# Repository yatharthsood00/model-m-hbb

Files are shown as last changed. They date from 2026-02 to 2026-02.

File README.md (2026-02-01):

# Model M Controller, by HBB

This is a drop-in replacement controller for the IBM Model M with QMK and VIAL support. I designed this for myself, and my own Models M, as well as some that I have sold/gifted to friends in the custom keyboard community, which is why this is designed only for the Models M that I own (the 101 key ANSI version, and the Space Saving Keyboard).

**Status (01-02-2026):** PCBA produced via JLCPCB and delivered. Tested successfully for basic operation. JST connector assembly in progress (I don't have a hot air soldering station).

## TODO:

1. Testing status lights and buzzer operation.
2. Uploading QMK and VIAL source to their respective repos.
3. BOM list availability in README (this file).
4. Fitment issue resolution due to USB-C port being too low for the existing cutout.
5. Figuring out solenoid operation and components required.
6. Pictures.

## Specs

- Based on the STM32F072CBT6 microcontroller, wide availability and great pedigree with QMK and VIAL. Works over USB-C.
- Like said, QMK and VIAL compatibility (firmware push and merge pending but it'll be there).
- Buzzer and Solenoid compatibility (optional, WIP). The exact parts needed for the solenoid are TBD and testing is required to be done first.
- Custom Status Lights PCB for adding LEDs in the colours of your choosing (standard DIP LEDs only), for the variants that have the possibility of adding such lights.
- Compatible with the 101-key and SSK Models M, Terminal or PS/2, both ANSI and ISO* versions.

*I need help with the firmware, as I don't own an ISO Model M to test it on.

## Why a new controller?

The "replacement Model M Controller" idea has already been implemented by many projects, with them already doing the work on understanding how the controller can be made in the first place, and the dimensions of a board that will fit the space voided by the original controller, that would be necessary to know how to place the components on my replacement. With that in mind, I would like to specifically highlight the [Ctrl-M](https://github.com/nuess0r/ctrl-M) and the [Model H](https://github.com/jhawthorn/modelh) projects, as they both provided me a sanity check of the dimensions of the PCB that I needed to design, separate from my own measurements of the several OEM controllers I now own.

While the above two are perfectly capable equivalents of my own creation, and I'm sure many would find either more suited for their own use cases, I found some limitations with the both of them that were disqualifying for my own use. Here is what I needed:

1. USB-C. All my other keyboards work off the same USB-C cable that I can detach from the keyboard end and swap the keyboard on my desk with another. While the Model H had this ability with the right Pro Micro controller, the Ctrl-M did not.
2. PCBA. It's significantly more expensive to produce this PCB via JLCPCB, with or without their assembly service. It's also almost conventional to expect a vintage keyboard replacement part to use a more "period-accurate" part selection, with through-hole componentry wherever possible, but I wanted something more modern that resembled a keyboard PCB you would get with a custom keyboard today. An entirely vain addition.
3. Additional bells and whistles. A keyboard with a solenoid is something I always wanted to add to my collection. While there are modern boards that will provide that to you, they are superseded, in my opinion, by a roomy plastic chassis, from a time when keyboards were normally significantly louer. Neither of the existing modules could provide that to me without a significant modification, so I decided to start from scratch.

Note: As a starting point for the solenoid and buzzer, I took directly from the [M122ion Control](https://github.com/dcpedit/mission-control) project, although the end result will use different components for the switching circuit.

All the above are fulfilled by this controller. This is also my first PCB design, and I enjoyed working on it. 

**As a disclaimer, however,** I don't claim this to be an extremely competent component, and I would advise anyone thinking of ordering a production run of this PCB to do their due diligence first. This is a hobbyist project first of all. Nonetheless, don't hesitate to reach out to me on @hardbodybrain on Discord, or on my personal email ID, yatharthsood00 [at] gmail [dot] com for any questions or clarifications, as well as if you want to share your experiences with this PCB, if you chose to get one of your own!

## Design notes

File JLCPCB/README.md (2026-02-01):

# JLCPCB Production Files

There are two folders - one for the Gerber files for the controller itself, and the other for the status lights PCB Gerber files. You can skip the latter if you own an SSK or a Terminal model with no ability to display any status LEDs.

Both these folders contain the same files I used for the first production run of this PCB, in January 2026. Read the main README.md file for information on the run's outcomes and how the PCBs fared in my testing.

### Controller PCB

- Expected to be PCBA. 
- Uses SMD components wherever possible. You are expected to mandatorily solder the ribbon connector receptacles, I didn't hold my breath for JLCPCB having them in their components library. 
- All solenoid parts (except for the solenoid JST) are also through-hole, as I was not sure about which ones to use to make the solenoid work when I placed the order.
- The STM32 microcontroller chip will come with the USB-based bootloader in my experience when ordered from JLCPCB, but the board lacks exposed serial debug pins which you need in case you don't have a controller with the required bootloader, requiring you to solder some wires to the chip directly (tricky business).
- All the settings are all the defaults from JLCPCB that automatically populate when you upload the production files archive, except for the surface finish (I went with lead-free HASL, although that limits you on colour choices).

### Status lights
- Expected not PCBA, but you will have to solder the JST yourself if not. If money is no object, you can pay the hefty fees to solder one (1) singular component on this board through the assembly service. 
- All other parts are THT and trivial to assemble yourself. You can pick your status LEDs and read their datasheets for knowing what resistance would be best to work with.
- All default JLCPCB settings. 

More information will be added as I can add it based on my own experiences with this PCB.

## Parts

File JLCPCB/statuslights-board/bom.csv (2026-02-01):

Designator | Footprint | Quantity | Value | LCSC Part #
CAPSLED, NUMLED, SCRLED | LED_D5.0mm | 3 | LED
CAPSR, NUMR, SCRR | R_Axial_DIN0204_L3.6mm_D1.6mm_P1.90mm_Vertical | 3 | 51R
J1 | JST_SH_BM04B-SRSS-TB_1x04-1MP_P1.00mm_Vertical | 1 | JST SH (from controller)

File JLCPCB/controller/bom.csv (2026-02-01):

Designator | Footprint | Quantity | Value | LCSC Part #
BZ1 | Buzzer_12x9.5RM7.6 | 1 | Buzzer
C1 | 0402 | 1 | 10uF | C52923
C10, C11, C2 | 0402 | 3 | 1uF | C52923
C3, C6, C8 | 0402 | 3 | 4.7uF
C4, C5, C7, C9 | 0402 | 4 | 100nF
D1 | D_DO-41_SOD81_P2.54mm_Vertical_AnodeUp | 1 | ~
D2 | SOT-143 | 1 | PRTR5V0U2X
F1 | 1206 | 1 | ASMD1206-050
J1 | USB_C_Receptacle_HRO_TYPE-C-31-M-12 | 1 | USB_C_Receptacle_USB2.0_16P
J2 | PinHeader_1x16_P2.54mm_Vertical | 1 | Conn_01x16_Socket
J3 | PinHeader_1x08_P2.54mm_Vertical | 1 | Conn_01x08_Socket
J4 | JST_SH_BM04B-SRSS-TB_1x04-1MP_P1.00mm_Vertical | 1 | JST SH 4-pin
J5 | JST_SH_BM02B-SRSS-TB_1x02-1MP_P1.00mm_Vertical | 1 | JST SH 2-pin
Q1 | SOT-23 | 1 | 2N7002
Q2 | TO-220-3_Vertical_BCE | 1 | ~
R1, R2 | 0402 | 2 | 5.1K
R3 | 0402 | 1 | 10K
R4 | 0402 | 1 | 100K
R5 | 0402 | 1 | 33K
R6, R7 | R_Axial_DIN0204_L3.6mm_D1.6mm_P1.90mm_Vertical | 2 | ~
SW1 | SW_Push_1P1T_XKB_TS-1187A | 1 | TS-1187A-B-A-B
U1 | SOT-23 | 1 | XC6206P332MR
U2 | LQFP-48_7x7mm_P0.5mm | 1 | STM32F072CBT6

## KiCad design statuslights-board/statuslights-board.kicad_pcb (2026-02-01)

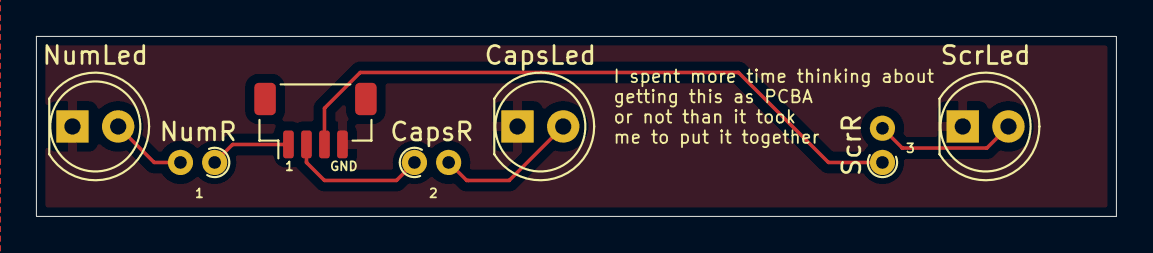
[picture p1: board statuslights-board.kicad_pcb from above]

Board: 2 copper layers, 60.0 x 10.0 mm, 7 parts (0 on the bottom side), 7 nets.

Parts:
CapsLed: LED; LED_D5.0mm
CapsR: 51R; R_Axial_DIN0204_L3.6mm_D1.6mm_P1.90mm_Vertical
J1: JST SH (from controller); JST_SH_BM04B-SRSS-TB_1x04-1MP_P1.00mm_Vertical
NumLed: LED; LED_D5.0mm
NumR: 51R; R_Axial_DIN0204_L3.6mm_D1.6mm_P1.90mm_Vertical
ScrLed: LED; LED_D5.0mm
ScrR: 51R; R_Axial_DIN0204_L3.6mm_D1.6mm_P1.90mm_Vertical

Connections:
CapsLk: CapsR.1, J1.2
GND: CapsLed.1 (K), J1.4, NumLed.1 (K), ScrLed.1 (K)
unnamed: CapsLed.2 (A), CapsR.2
unnamed: NumLed.2 (A), NumR.2
unnamed: ScrLed.2 (A), ScrR.2
NumLk: J1.1, NumR.1
ScrLk: J1.3, ScrR.1

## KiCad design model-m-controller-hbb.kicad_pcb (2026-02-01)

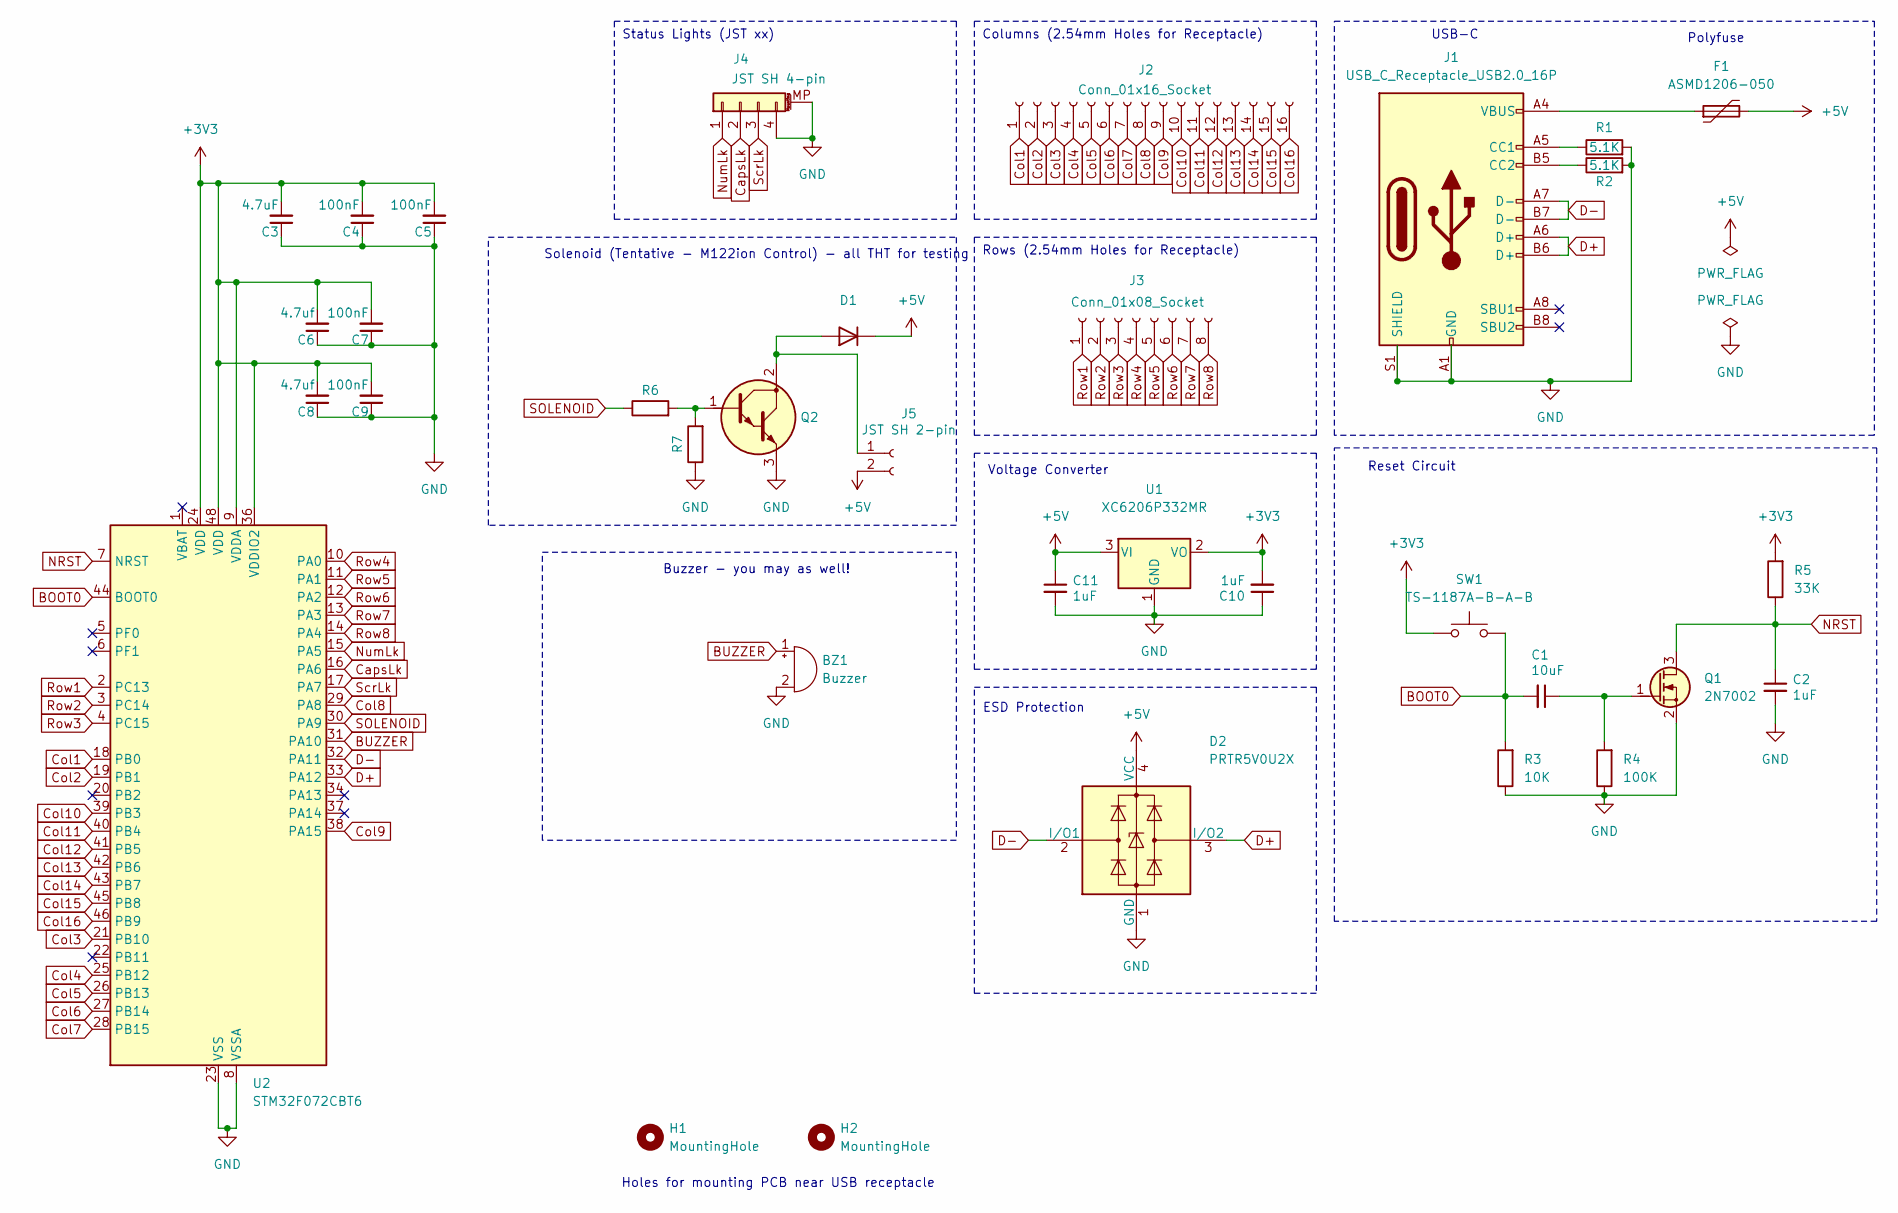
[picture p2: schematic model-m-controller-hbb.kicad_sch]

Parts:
BZ1: Buzzer; Buzzer_12x9.5RM7.6
C1: 10uF; C_0402_1005Metric; MPN CL05A105KA5NQNC; LCSC C52923
C2, C10, C11: 1uF; C_0402_1005Metric; MPN CL05A105KA5NQNC; LCSC C52923
C3: 4.7uF; C_0402_1005Metric
C4, C5, C7, C9: 100nF; C_0402_1005Metric
C6, C8: 4.7uf; C_0402_1005Metric
D1: D_DO-41_SOD81_P2.54mm_Vertical_AnodeUp
D2: PRTR5V0U2X; SOT-143; MPN PRTR5V0U2X
F1: ASMD1206-050; Fuse_1206_3216Metric
H1, H2: MountingHole; MountingHole_4mm
J1: USB_C_Receptacle_USB2.0_16P; USB_C_Receptacle_HRO_TYPE-C-31-M-12
J2: Conn_01x16_Socket; PinHeader_1x16_P2.54mm_Vertical
J3: Conn_01x08_Socket; PinHeader_1x08_P2.54mm_Vertical
J4: JST SH 4-pin; JST_SH_BM04B-SRSS-TB_1x04-1MP_P1.00mm_Vertical
J5: JST SH 2-pin; JST_SH_BM02B-SRSS-TB_1x02-1MP_P1.00mm_Vertical
Q1: 2N7002; SOT-23
Q2: TO-220-3_Vertical_BCE
R1, R2: 5.1K; R_0402_1005Metric
R3: 10K; R_0402_1005Metric
R4: 100K; R_0402_1005Metric
R5: 33K; R_0402_1005Metric
R6, R7: R_Axial_DIN0204_L3.6mm_D1.6mm_P1.90mm_Vertical
SW1: TS-1187A-B-A-B; SW_Push_1P1T_XKB_TS-1187A
U1: XC6206P332MR; SOT-23; MPN XC6206P332MR-G
U2: STM32F072CBT6; LQFP-48_7x7mm_P0.5mm

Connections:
+3V3: C3.2, C4.2, C5.2, C6.2, C7.2, C8.2, C9.2, C10.2, R5.2, SW1.1, U1.2 (VO), U2.9 (VDDA), U2.24 (VDD), U2.36 (VDDIO2), U2.48 (VDD)
+5V: C11.1, D1.1 (K), D2.4 (VCC), F1.2, J5.2, U1.3 (VI)
BOOT0: C1.2, R3.2, SW1.2, U2.44 (BOOT0)
BUZZER: BZ1.1 (+), U2.31 (PA10)
CapsLk: J4.2, U2.16 (PA6)
Col1: J2.1, U2.18 (PB0)
Col2: J2.2, U2.19 (PB1)
Col3: J2.3, U2.21 (PB10)
Col4: J2.4, U2.25 (PB12)
Col5: J2.5, U2.26 (PB13)
Col6: J2.6, U2.27 (PB14)
Col7: J2.7, U2.28 (PB15)
Col8: J2.8, U2.29 (PA8)
Col9: J2.9, U2.38 (PA15)
Col10: J2.10, U2.39 (PB3)
Col11: J2.11, U2.40 (PB4)
Col12: J2.12, U2.41 (PB5)
Col13: J2.13, U2.42 (PB6)
Col14: J2.14, U2.43 (PB7)
Col15: J2.15, U2.45 (PB8)
Col16: J2.16, U2.46 (PB9)
D+: D2.3 (I/O2), J1.A6 (D+), J1.B6 (D+), U2.33 (PA12)
D-: D2.2 (I/O1), J1.A7 (D-), J1.B7 (D-), U2.32 (PA11)
GND: BZ1.2 (-), C2.2, C3.1, C4.1, C5.1, C6.1, C7.1, C8.1, C9.1, C10.1, C11.2, D2.1 (GND), J1.A1 (GND), J1.A12 (GND), J1.B1 (GND), J1.B12 (GND), J1.S1 (SHIELD), J4.4, J4.MP (MountPin), Q1.2 (S), Q2.3 (E), R1.2, R2.2, R3.1, R4.1, R7.1, U1.1 (GND), U2.8 (VSSA), U2.23 (VSS), U2.35 (VSS), U2.47 (VSS)
NRST: C2.1, Q1.3 (D), R5.1, U2.7 (NRST)
unnamed: D1.2 (A), J5.1, Q2.2 (C)
unnamed: F1.1, J1.A4 (VBUS), J1.A9 (VBUS), J1.B4 (VBUS), J1.B9 (VBUS)
unnamed: J1.A5 (CC1), R1.1
unnamed: J1.B5 (CC2), R2.1
unnamed: C1.1, Q1.1 (G), R4.2
unnamed: Q2.1 (B), R6.2, R7.2
NumLk: J4.1, U2.15 (PA5)
Row1: J3.1, U2.2 (PC13)
Row2: J3.2, U2.3 (PC14)
Row3: J3.3, U2.4 (PC15)
Row4: J3.4, U2.10 (PA0)
Row5: J3.5, U2.11 (PA1)
Row6: J3.6, U2.12 (PA2)
Row7: J3.7, U2.13 (PA3)
Row8: J3.8, U2.14 (PA4)
SOLENOID: R6.1, U2.30 (PA9)
ScrLk: J4.3, U2.17 (PA7)

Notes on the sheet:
Columns (2.54mm Holes for Receptacle)
Status Lights (JST xx)
Rows (2.54mm Holes for Receptacle)
Holes for mounting PCB near USB receptacle
Polyfuse
Voltage Converter
ESD Protection
Reset Circuit
Solenoid (Tentative - M122ion Control) - all THT for testing
USB-C
Buzzer - you may as well!

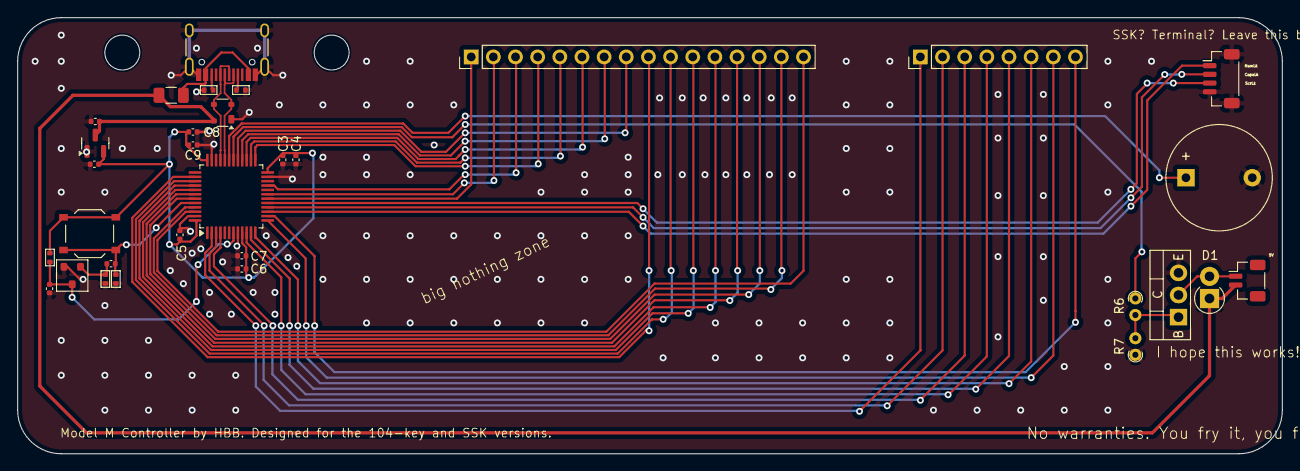
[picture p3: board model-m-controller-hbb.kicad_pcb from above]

Board: 2 copper layers, 145.0 x 50.0 mm, 34 parts (0 on the bottom side), 42 nets.

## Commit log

2026-02-01 Inital Commit, after v1 Production
    [bom.csv, designators.csv, model-m-controller-hbb.kicad_pcb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]
2026-02-01 Added Status Lights files and project
    [bom.csv, designators.csv, positions.csv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]
2026-02-01 Added main and gerber README files
